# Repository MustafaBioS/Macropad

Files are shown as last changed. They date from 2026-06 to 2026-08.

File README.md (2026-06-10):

# Macropad
Macropad is a hardware project that allows you to bind keys to do certain tasks on your PC

# Why
Because it's a cool project and its also very usefuL!

# Components
This project uses the following:
- SEEDUINO-XIAO MCU
- 4 Tactile Switches
- Rotary Encoder Switch
- 128x32 OLED Display

# Schematic, PCB, 3D Model, and Zine!

## Schematic


## PCB



## 3D Model


## Zine
A5 - 1 (3)

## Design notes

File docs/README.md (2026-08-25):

# What is Macropad
Macropad is a hardware project that allows you to bind keys to do certain tasks on your PC

# Why
I built Macropad as it's a really cool project and its also very useful because i needed one anyway.

# How To Use?
Each button is **programmed to do a certain task** on your device, you can also **change layers** so that each button's programmed task is changed to another task.
You can also use the **Rotary Encoder** to change the volume of your device, And there's an **OLED Display** that shows you what your pressed button did!

# How To Recreate
## Components
This project uses the following:
- **SEEDUINO-XIAO MCU**
- **4 Tactile Switches**
- **Rotary Encoder Switch**
- **128x32 OLED Display**

## Bill Of Materials
| **Item** | **Price** | **Link** |
| --- | --- | --- |
| `SEEDUINO-XIAO` | $8.69 | [Link](https://www.amazon.eg/-/en/Seeed-XIAO-RP2040-Development-Board/dp/B0GHNR74YH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) |
| `4X Tactile Switches` | $2.63 | [Link](https://www.amazon.eg/gp/product/B0DRGP5733/ref=ewc_pr_img_3?smid=A2DMKAT7ZKLGQN&psc=1) |
| `128x32 OLED DISPLAY + Rotary Encoder` | $9.10 | [Link](https://www.amazon.eg/-/en/Display-Interface-construction-installation-Reliable/dp/B0GXQCMJS1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) |
| `PCB Fab` | $2.00 | [Link](https://cart.jlcpcb.com/quote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) |
| `Total` | $22.42 | None |

# Schematic, PCB, 3D Model, and Zine!

## Schematic


## PCB



## 3D Model


## Zine
zine

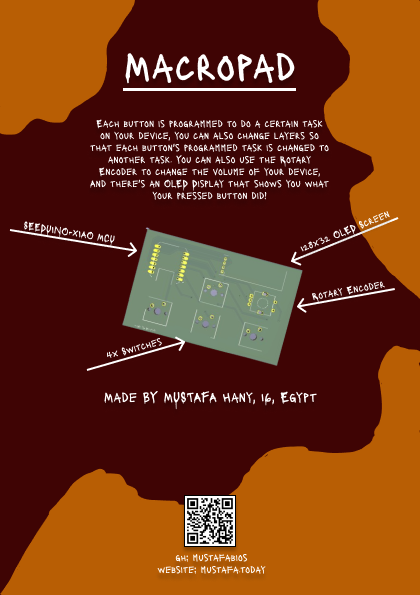
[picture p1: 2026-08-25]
docs/zine.png

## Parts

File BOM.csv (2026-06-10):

Item: | Price: | Link:
SEEDUINO-XIAO | $8.69 | https://www.amazon.eg/-/en/Seeed-XIAO-RP2040-Development-Board/dp/B0GHNR74YH
4X Tactile Switches | $2.63 | https://www.amazon.eg/gp/product/B0DRGP5733/ref=ewc_pr_img_3?smid=A2DMKAT7ZKLGQN&psc=1
128x32 OLED DISPLAY + Rotary Encoder | $9.10 | https://www.amazon.eg/-/en/Display-Interface-construction-installation-Reliable/dp/B0GXQCMJS1
Total: | $20.42

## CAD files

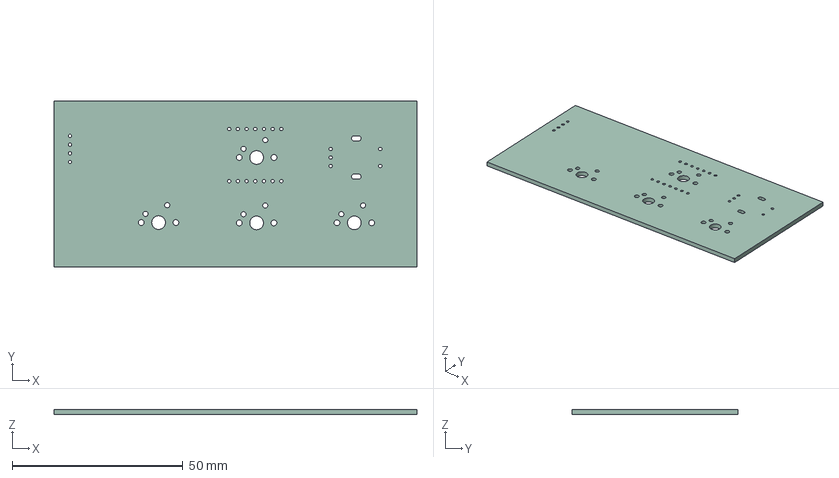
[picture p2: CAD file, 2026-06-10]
model/Macropad.step
106.2 x 48.5 x 1.51 mm

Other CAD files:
model/Macropad.f3d

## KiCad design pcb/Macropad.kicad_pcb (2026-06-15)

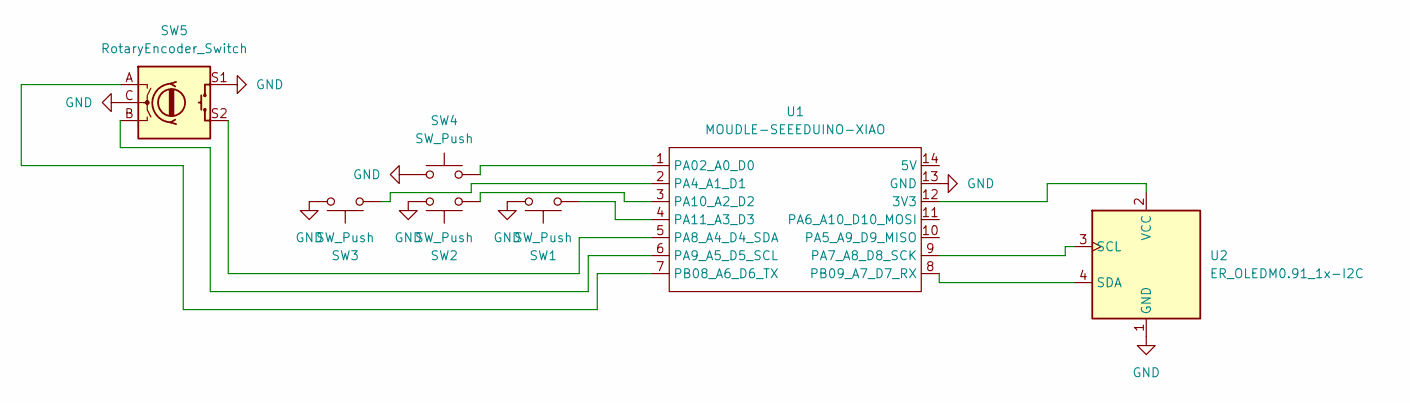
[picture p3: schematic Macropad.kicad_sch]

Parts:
SW1, SW2, SW3, SW4: SW_Push; SW_Cherry_MX_1.50u_PCB
SW5: RotaryEncoder_Switch; RotaryEncoder_Alps_EC11E-Switch_Vertical_H20mm
U1: MOUDLE-SEEEDUINO-XIAO; XIAO-Generic-Hybrid-14P-2.54-21X17.8MM
U2: ER_OLEDM0.91_1x-I2C

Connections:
GND: SW1.2, SW2.2, SW3.2, SW4.1, SW5.C, SW5.S1, U1.13 (GND), U2.1 (GND)
unnamed: U1.12 (3V3), U2.2 (VCC)
unnamed: SW4.2, U1.1 (PA02_A0_D0)
unnamed: SW3.1, U1.2 (PA4_A1_D1)
unnamed: U1.9 (PA7_A8_D8_SCK), U2.3 (SCL)
unnamed: SW5.S2, U1.5 (PA8_A4_D4_SDA)
unnamed: SW5.B, U1.6 (PA9_A5_D5_SCL)
unnamed: SW2.1, U1.3 (PA10_A2_D2)
unnamed: SW1.1, U1.4 (PA11_A3_D3)
unnamed: SW5.A, U1.7 (PB08_A6_D6_TX)
unnamed: U1.8 (PB09_A7_D7_RX), U2.4 (SDA)

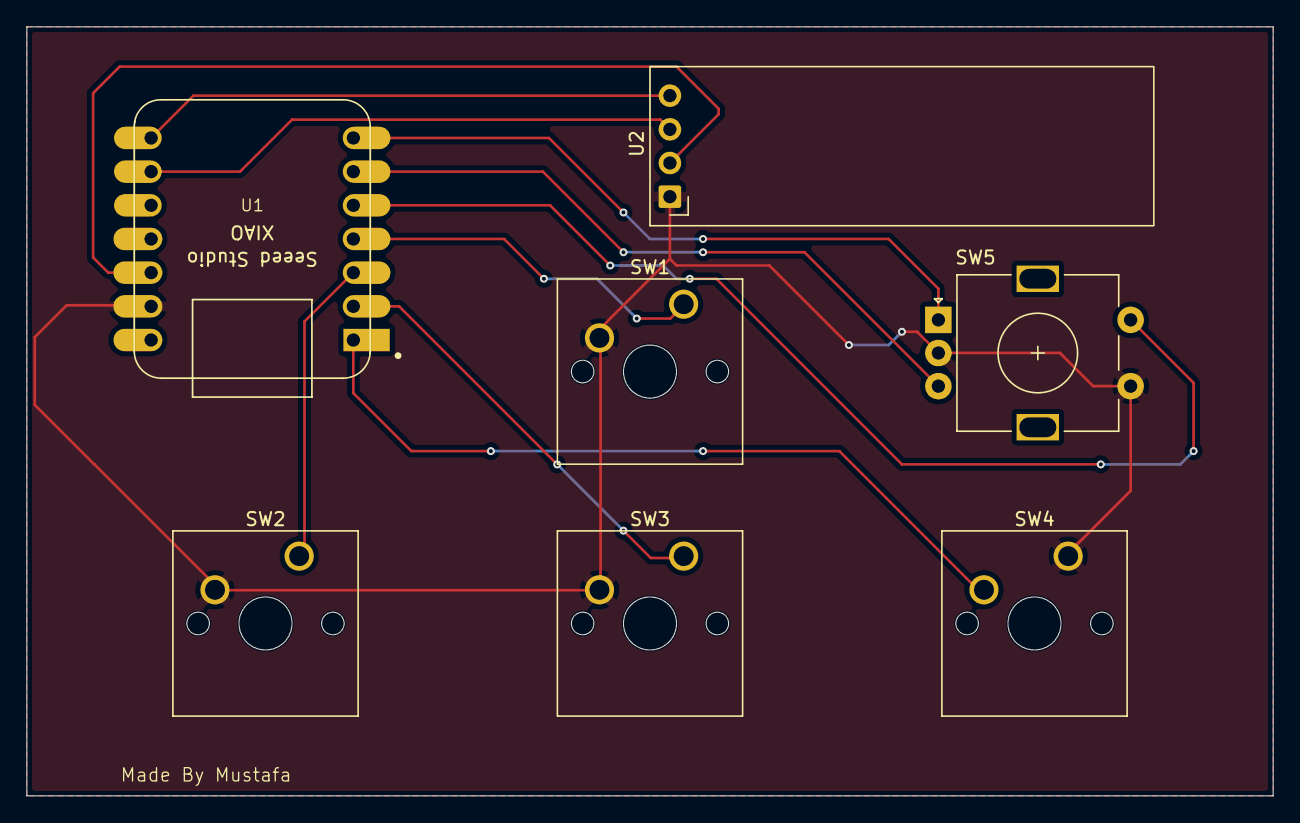
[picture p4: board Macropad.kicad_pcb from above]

Board: 2 copper layers, 94.0 x 58.0 mm, 7 parts (0 on the bottom side), 11 nets.

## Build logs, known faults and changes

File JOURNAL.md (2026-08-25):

<!--
  This journal is auto generated by Stasis.
-->

# 8/26/2026 12 AM - Fixing Zine (#2) [link](https://lapse.hackclub.com/timelapse/Cam4m-gLrUOj)

_Time spent: 0.2h_

Fixed the zine by removing the HackPad png and adding my own pcb on the zine.

zine

# 6/23/2026 12 AM - Fallout Rejection Requirements (#2) [link](https://lapse.hackclub.com/timelapse/A10IVLgfQrgS)

_Time spent: 0.2333333333333333h_

Fixed the github repository bill of materials (BOM.csv) file and the README.md file in the github repository for my macropad project as requested by the fallout project reviewer!





# 6/23/2026 12 AM - Fallout Rejection Requirements [link](https://lapse.hackclub.com/timelapse/BqaLo_dcaIBQ)

_Time spent: 0.45h_

Added some of the requirements like the PCB ground pour, also fixed the xiao location so it's easily accessible with a USB cable, used 1.0u switch footprint instead of 1.5u!





# 6/23/2026 12 AM - More Polishing [link](https://lapse.hackclub.com/timelapse/JMibOLBedjtg)

_Time spent: 0.1833333333333333h_

Did some more polishing as i forgot to add the .gerber files to my repository, and i also fixed my zine a bit more by explaining what the project does in it and added some arrows explaining each component!

A5 - 1 (6)



# 6/23/2026 12 AM - Zine [link](https://lapse.hackclub.com/timelapse/R-0Jus2_Yv6s)

_Time spent: 1.05h_

Added final polishing to the repo as required by the submitting check thingy on fallout, i created a Zine, fixed the README.md issues, added all the required files, and organized them in folders so that the repository looks clean!



A5 - 1 (3)




# 6/23/2026 12 AM - CAD (#2) [link](https://lapse.hackclub.com/timelapse/GbEgRaOs2O8a)

_Time spent: 1.016666666666667h_

Tried finishing up the 3D model and kinda succeeded???? i sure understand alot more about fusion360 and 3d modelling now, although the case doesn't look that good but i think it's the best i can do, i also did part of the README.md, i'll finish it up once i finish the rest of the stuff and polish my project a bit more





# 6/23/2026 12 AM - CAD [link](https://lapse.hackclub.com/timelapse/e7k9q_7EdBzw)

_Time spent: 0.5333333333333333h_

Tried designing the 3d case for the macorpad on fusion360, it was honestly too hard and i couldn't figure it out at all, i'll probably watch a youtube tutorial on the basics of fusion360 before continuing this case, i also feel like something is wrong with the measurements for some reason.





# 6/23/2026 12 AM - Polishing and Added a Screen [link](https://lapse.hackclub.com/timelapse/G2zCbI1jcRYN)

_Time spent: 0.8166666666666667h_

Did some final polishing on the code, Schematic, and PCB Design. i also added an OLED screen to display text when a macropad button is clicked, will hopefully make it do more in the future like display graphic animations or something cool like that, but for now it's just text!











# 6/23/2026 12 AM - Firmware [link](https://lapse.hackclub.com/timelapse/aX2tP91TWLMV)

_Time spent: 0.9166666666666666h_

**(PLEASE DELETE THE PART WHERE I WAS WATCHING TIKTOK AND DON'T COUNT THE TIME FOR THAT I DIDN'T NOTICE IT WHILE EDITING THE LAPSE SOBBB)**

Began working on the firmware code and finished it, i also fixed a few problems in the schematic and PCB and added Edge Cuts, did alot of research here because i was unsure whether to use QMK, KMK, or a few other libraries, it all seemed to hard so and i wanted to use the Arduino IDE lol so i thought i'd go with Arduino HID Project for the Macropad library!





# 6/23/2026 12 AM - PCB Design and Schematic [link](https://lapse.hackclub.com/timelapse/fMZTNE3fEBID)

_Time spent: 1.166666666666667h_ 

Finished making the PCB Design and Schematic for the Macropad, it's my first time using kicad after using EasyEDA for all of my other projects so yeah.








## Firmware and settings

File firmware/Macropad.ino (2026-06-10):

#include <Wire.h>
#include <Adafruit_SSD1306.h>
#include <Adafruit_GFX.h>
#include <Keyboard.h>
#include <HID-Project.h>
#include <Encoder.h>

const int SW_4 = 2;
const int SW_3 = 3;
const int SW_2 = 4;
const int SW_1 = 5;

const int ENC_SWITCH = 6;

const int SCL_PIN = 8;
const int SDA_PIN = 20;

Encoder encoder(7, 21);

int layer = 0;
long position;

#define SCREEN_WIDTH 128
#define SCREEN_HEIGHT 32

#define OLED_RESET -1
#define SCREEN_ADDRESS 0x3C

Adafruit_SSD1306 display(SCREEN_WIDTH, SCREEN_HEIGHT, &Wire, OLED_RESET);

void showMessage(String msg) {
  display.clearDisplay();
  display.setTextSize(1);
  display.setTextColor(SSD1306_WHITE);
  display.setCursor(0,0);
  display.println(msg);
  display.display();
}

void setup() {
  Serial.begin(9600);

  delay(500);

  Wire.setSCL(SCL_PIN);
  Wire.setSDA(SDA_PIN);

  if (!display.begin(SSD1306_SWITCHCAPVCC, SCREEN_ADDRESS)) {
    Serial.println("Failed to start");
    for(;;);
  }

  display.display();
  delay(2000);

  display.clearDisplay();

  Keyboard.begin();
  Consumer.begin();

  pinMode(SW_4, INPUT_PULLUP);
  pinMode(SW_3, INPUT_PULLUP);
  pinMode(SW_2, INPUT_PULLUP);
  pinMode(SW_1, INPUT_PULLUP);

  pinMode(ENC_SWITCH, INPUT_PULLUP);

  // Initialize encoder position to avoid volume changes on startup
  position = encoder.read() / 4;
}

void loop() {

  // Encoder Volume Control
  long newPosition = encoder.read() / 4;

  if (newPosition != position) {

    if (newPosition > position) {
      Consumer.write(MEDIA_VOLUME_UP);
    }
    else if (newPosition < position) {
      Consumer.write(MEDIA_VOLUME_DOWN);
    }

    showMessage("Volume: " + String(newPosition));

    position = newPosition;
  }

  // SW_4 - Change Layer
  if (digitalRead(SW_4) == LOW) {

    while (digitalRead(SW_4) == LOW) {
      // Wait for release
    }

    if (layer != 2) {
      layer++;
    }
    else {
      layer = 0;
    }

    showMessage("Layer: " + String(layer));

    delay(20);
  }

  // SW_3
  if (digitalRead(SW_3) == LOW) {

    while (digitalRead(SW_3) == LOW) {
      // Wait for release
    }

    if (layer == 0) {
      Keyboard.press(KEY_LEFT_CTRL);
      Keyboard.press('c');
      delay(100);
      Keyboard.releaseAll();

      showMessage("Copied!");
    }
    else if (layer == 1) {

    }
    else if (layer == 2) {

    }

    delay(20);
  }

  // SW_2
  if (digitalRead(SW_2) == LOW) {

    while (digitalRead(SW_2) == LOW) {
      // Wait for release
    }

    if (layer == 0) {
      Keyboard.press(KEY_LEFT_CTRL);
      Keyboard.press('v');
      delay(100);
      Keyboard.releaseAll();

      showMessage("Pasted!");
    }
    else if (layer == 1) {

    }
    else if (layer == 2) {

    }

    delay(20);
  }

  // SW_1
  if (digitalRead(SW_1) == LOW) {

    while (digitalRead(SW_1) == LOW) {
      // Wait for release
    }

    if (layer == 0) {
      Keyboard.press(KEY_LEFT_ALT);
      Keyboard.press(KEY_TAB);
      delay(100);
      Keyboard.releaseAll();

      showMessage("Switched Tab!");
    }
    else if (layer == 1) {

    }
    else if (layer == 2) {

    }

    delay(20);
  }

  // Encoder Button - Mute
  if (digitalRead(ENC_SWITCH) == LOW) {

    while (digitalRead(ENC_SWITCH) == LOW) {
      // Wait for release
    }

    Consumer.write(MEDIA_VOLUME_MUTE);

    showMessage("Muted Audio!");

    delay(20);
  }
}
